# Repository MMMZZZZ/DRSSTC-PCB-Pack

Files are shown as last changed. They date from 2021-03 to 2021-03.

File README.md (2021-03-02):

I created a [new version of the UD2.7 THT](/ud27c%20thru%20hole#readme). No other changes, so here's the original readme:

Dual Resonant Solid State Tesla Coil and Solid State Tesla Coil PCB pack.
Copyright (C) 2018 by Daniel L. Marks, licensed under the Created Commons CC-BY-SA 4.0.

These are PCBs for use in DRSSTC/SSTC devices.  They are projects using
the free and open source Kicad software (kicad-pcb.org) version 4.0.7, so these projects
may be modified using this software.  Each file includes the following:

1.  Kicad project, so it can be modified or improved
2.  PDF Schematic
3.  Bill of materials, to refer to when assembling
4.  PNG circuit board picture, to refer to when assembling
5.  Gerber files

The projects, except for the interrupters, are 100 by 100 mm boards with 90 by 90 mm
mounting hole spacing.  These boards may be stacked using M3 spacers. Board of this 
size can often be fabricated for $5 (without shipping) from PCB manufacturers such as
Seeedstudio.  You can save on shipping per board if you have several of
these made at a time, for example, the driver, interrupter, and a bridge board.  

The projects are as follows:

ud27c - a through hole version of the Universal Tesla coil driver, version 2.7C.
          This is based on a design originally by Steve Ward and refined by others including
          Eric Goodchild and Gao Guangyan.  It has substituted the through-hole parts 
          IRF540N/IRF9540N complementary MOSFET pair for the FDD8424H dual MOSFET part.
          It includes phase lead, unlike the Universal Driver v1.3.

ud29 - an experimental version of ud27c that includes skip pulse functionality.  Pulse skip is
          enabled or disabled using a jumper, so it may be used as a normal DRSSTC controller.
		  The board has been built and worked for my coil.
		  
PSoc5-power - a through-hole version of the Universal Driver 3 by Steve Ward and Jens Kerrinnes
          based on the PSoC5 system-on-chip. This includes the functionality for temperature,
		  bus voltage, and bus current sensing.	 This is experimental.  It uses the CYC8KIT-059
		  dev board plugged into the PCB using pin header sockets.

interrupter - a DRSSTC interrupter based on Steve Ward's burst mode interrupter.  It
          includes a place for the IFE97 LED optical fiber transmission unit.  The ability
          to include an external pulse trigger signal has been included for use with audio
          sources.  Also includes a spot on the board for a OneTesla 
		  ATTINY85-based MIDI interrupter which may be flashed with the OneTesla code through
		  the ICSP interface.

lineinterrupter - an experimental interrupter that interrupts on the peak of the AC cycle.
           Interrupting only at the peak of the AC cycle is intended to improve the power factor
		   by minimizing the inrush of current into the bus capacitors as the magnitude of
		   the voltage increases.  
		  
NOTE: You need to flash the included firmware on your ATTINY85 for the MIDI interrupter to work.
Instructions are in the folder "oneTesla-usbInterrupter-software".
		  
half-bridge-sstc - a half-bridge/full-bridge driver designed by myself
          that can either self-oscillate, or take an extetrnal antenna input from a
          Solid State Tesla Coil.  It includes overcurrent and undervoltage protection.
	  
half-bridge-transistor - a layout for a two TO-247 transistor half-bridge that includes
          an area for the capacitor divider network.  Note the polarity on the gates indicated
          on the silkscreening always indicates the negative and positive voltage side of
          the gate; wire the phases of the gates accordingly (oppositely in this case).  This
          convention is followed for all of the layouts.  Space is included for both
          supply bypass/DC Link capacitors and snubber capacitors.
	  
full-bridge-transistor - a layout for a four TO-247 transistor full-bridge.  Space is included
          for supply bypass DC/Link capacitors and snubber capacitors.  The two high-side gates
          should have their polarities wired oppositely, the two low-side gates should
          have their polarities wired oppositely, and the high and low-side gates of each half-bridge
          should be have their polarities wired oppositely.
	  
half-bridge-multi - a layout for an eight TO-247 transistor half-bridge, with four transistors
          of each side of the half-bridge.  The transistors should have a positive temperature
          coefficient to share current more equally.  The high and low-side gates should have their
          polarities wired oppositely.
	  
full-bridge-multi - a layout for an eight TO-247 transistor full-bridge, with two transistors on
          each side of each half bridge.  The two high-side gates should have their 
          polarities wired oppositely, the two low-side gates should have their polarities
          wired oppositely, and the high and low-side gates of each half-bridge
	      should be have their polarities wired oppositely.

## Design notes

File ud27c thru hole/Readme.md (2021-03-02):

# UD2.7 Through Hole

## Description

This folder contains the KiCad files for the through hole edition of the UD2.7 DRSSTC driver. It uses the schematic and the footprints from the original UD2.7 THT profdc9 made. However, the layout is completely new.

Features:

* PCB can be manufactured as standard double sided PCB *and* as **single sided**. 
	* Top layer only contains straight connections that can be replaced by jumper wires. Note that this assumes you're using sockets for the ICs.
	* No layout modifications needed for single or double side manufacturing. 
	* Single side should be easier to manufacture at home. 
* All TO220 parts are on the same side of the PCB. One common (isolated!) heatsink can be used.
* Optical inputs and status LEDs are on the opposite side of the heatsink. All inputs are grouped on the left side, the GDT output is on the right.
* All testpoints are on the edge of the PCB. 
* All terminals, jumpers and tespoints are labeled. DC In and testpoints have the pinout marked as well.
* PCB size: 99mm x 99mm
* [Interactive BOM](http://htmlpreview.github.io/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). An HTML document that allows you to visualize what part sits where. Great help during assembly! It allows highlighting nets, too, which is very useful for debugging. If you want to use it offline, right click and save as on the following link: [Interactive BOM, raw file](https://github.com/MMMZZZZ/DRSSTC-PCB-Pack/raw/master/ud27c%20thru%20hole/bom/ud27c%20Interactive%20BOM.html).

## Preview

Here are some pics. Since the layout was made with single side manufacturing in mind, the routing doesn't look that clean but it should work. Power and ground are somewhat star like. 

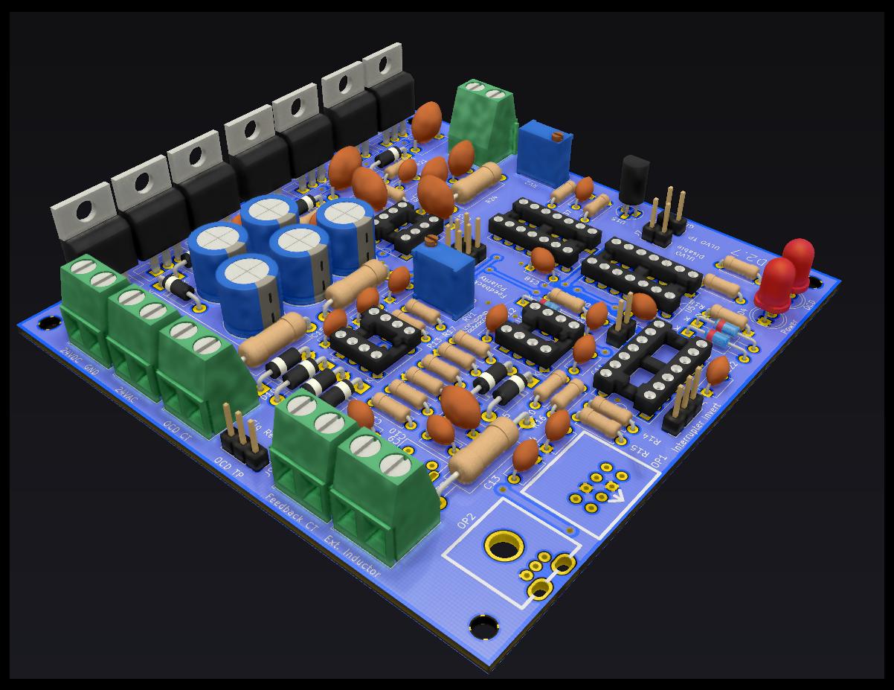
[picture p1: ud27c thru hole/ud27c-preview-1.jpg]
UD2.7 THT Rendering 1


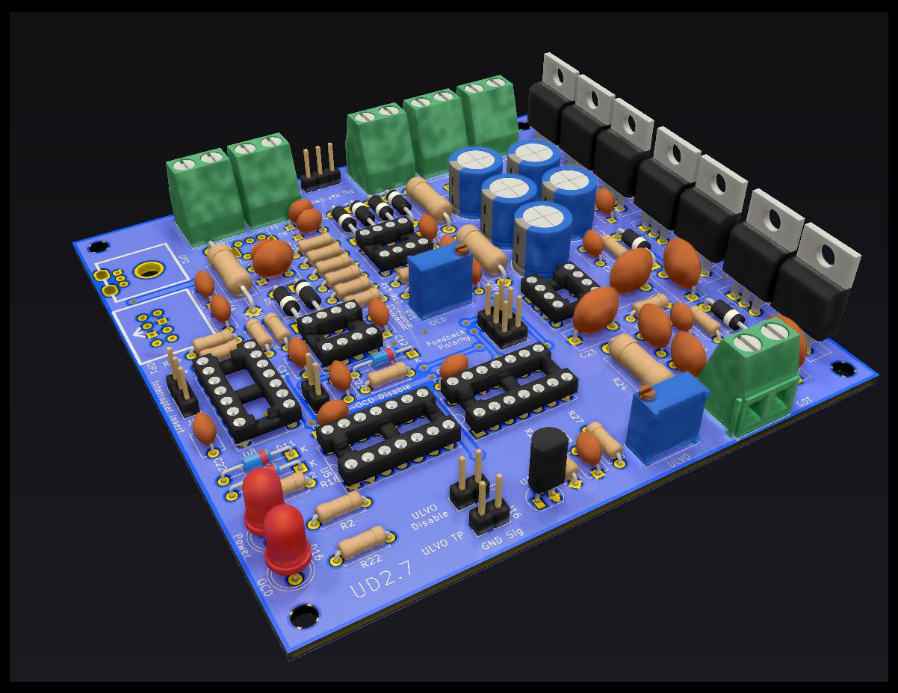
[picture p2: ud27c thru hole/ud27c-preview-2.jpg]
UD2.7 THT Rendering 2


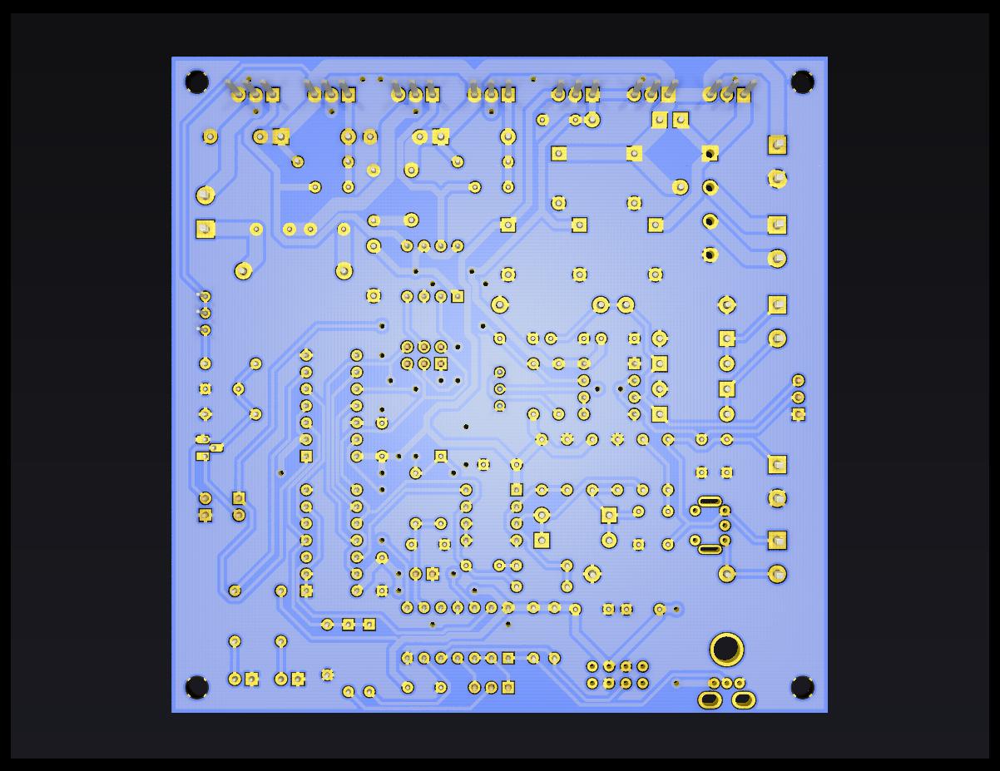
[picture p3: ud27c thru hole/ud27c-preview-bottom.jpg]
UD2.7 THT Bottom


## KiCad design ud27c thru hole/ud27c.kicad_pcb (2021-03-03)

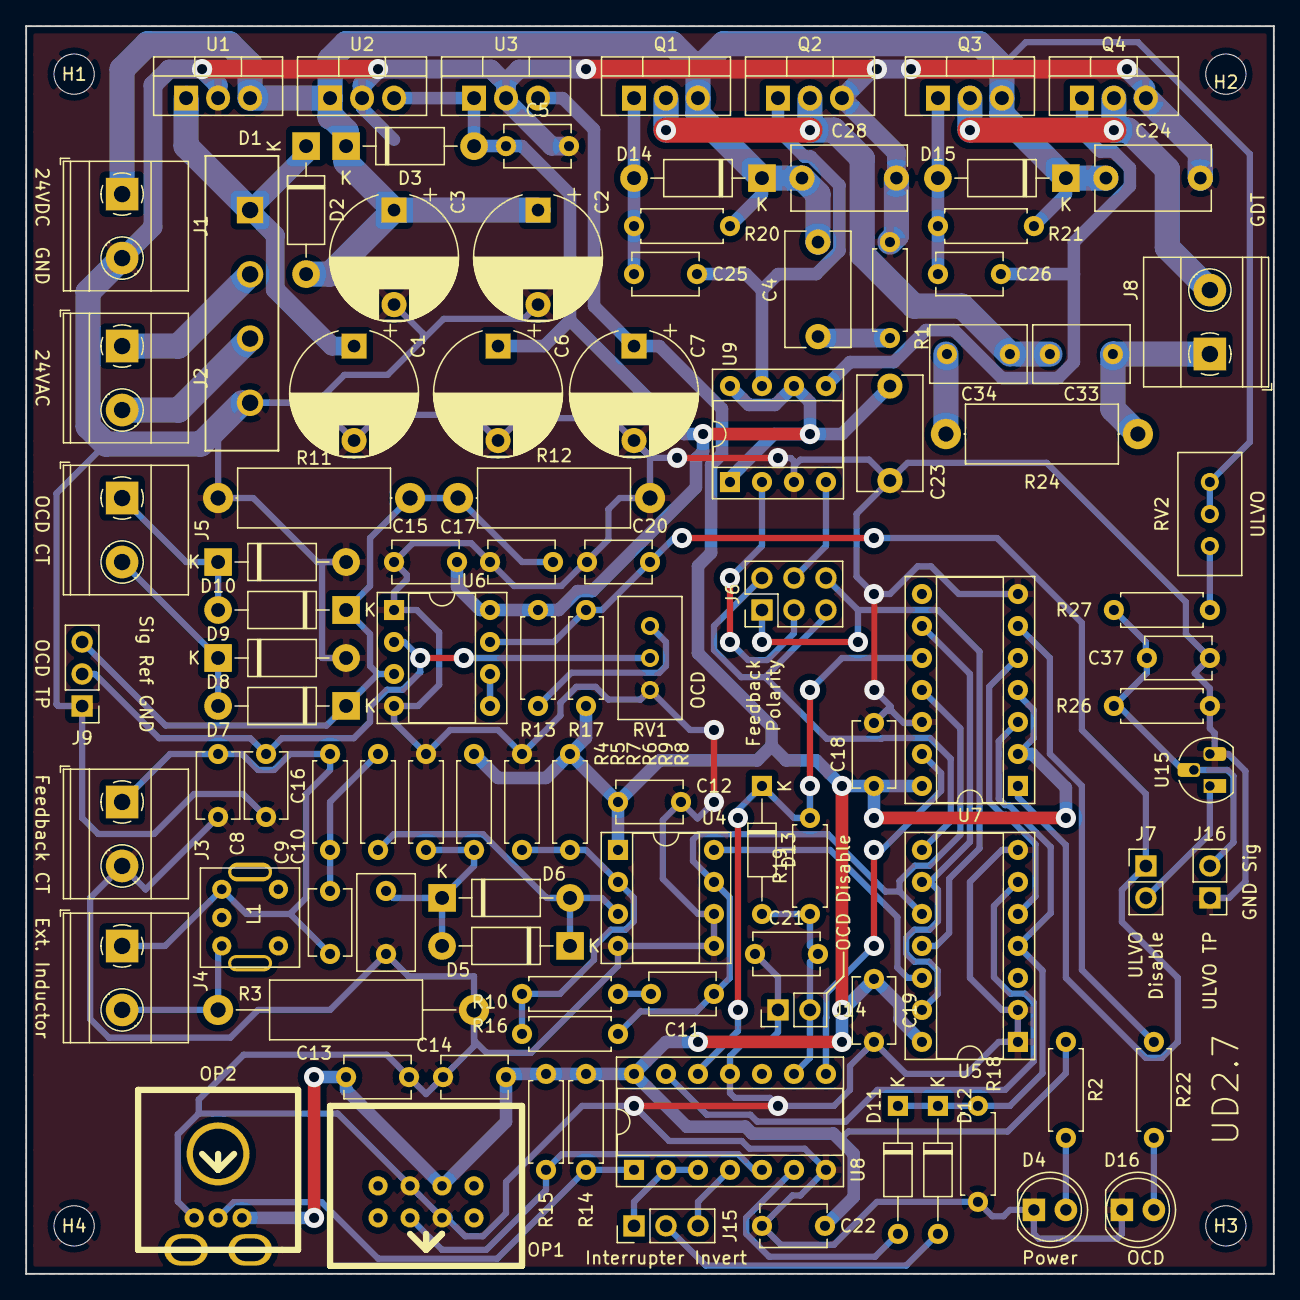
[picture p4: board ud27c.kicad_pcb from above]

Board: 2 copper layers, 99.1 x 99.1 mm, 106 parts (0 on the bottom side), 55 nets.

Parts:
C1, C2, C3: 100 uF; CP_Radial_D10.0mm_P7.50mm
C4, C24, C28: 4.7 uF; C_Disc_D9.0mm_W5.0mm_P7.50mm
C5, C9, C12, C13, C14, C15, C16, C18, C19, C22, C25, C26: 0.1 uF; C_Disc_D5.1mm_W3.2mm_P5.00mm
C6, C7: 330 uF; CP_Radial_D10.0mm_P7.50mm
C8: 150 pF; C_Disc_D5.1mm_W3.2mm_P5.00mm
C10, C34: 1 uF; C_Disc_D7.5mm_W4.4mm_P5.00mm
C11, C17, C20, C37: 1 nF; C_Disc_D5.1mm_W3.2mm_P5.00mm
C21: 10 nF; C_Disc_D5.1mm_W3.2mm_P5.00mm
C23: 1.0 uF; C_Disc_D9.0mm_W5.0mm_P7.50mm
C33: 2.2 uF; C_Disc_D7.5mm_W4.4mm_P5.00mm
D1: D_Bridge_-AA+; Diode_Bridge_18.5x5.5_4321
D2, D3: 1N4007; D_DO-41_SOD81_P10.16mm_Horizontal
D4: PWR-LED; LED_D5.0mm
D5, D6, D7, D8, D9, D10: 1N5818; D_DO-41_SOD81_P10.16mm_Horizontal
D11, D12, D13: 1N4148; D_DO-35_SOD27_P10.16mm_Horizontal
D14, D15: 1N4148; D_DO-41_SOD81_P10.16mm_Horizontal
D16: OCD-LED; LED_D5.0mm
H1, H2, H3, H4: MountingHole_Pad; MountingHole_3.2mm_M3
J1: +24V-; TerminalBlock_Phoenix_MKDS-1,5-2-5.08_1x02_P5.08mm_Horizont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
J2: 24VAC; TerminalBlock_Phoenix_MKDS-1,5-2-5.08_1x02_P5.08mm_Horizont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
J3: FB-CT; TerminalBlock_Phoenix_MKDS-1,5-2-5.08_1x02_P5.08mm_Horizont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
J4: FB-IND; TerminalBlock_Phoenix_MKDS-1,5-2-5.08_1x02_P5.08mm_Horizont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
J5: OCD-CT; TerminalBlock_Phoenix_MKDS-1,5-2-5.08_1x02_P5.08mm_Horizont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
J6: FB-POLARITY; PinHeader_2x03_P2.54mm_Vertical
J7: UV-DIS; PinHeader_1x02_P2.54mm_Vertical
J8: GDT; TerminalBlock_Phoenix_MKDS-1,5-2-5.08_1x02_P5.08mm_Horizont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
J9: OCD-TP; PinHeader_1x03_P2.54mm_Vertical
J14: OCD-DIS; PinHeader_1x02_P2.54mm_Vertical
J15: INT-POLARITY; PinHeader_1x03_P2.54mm_Vertical
J16: UV-TP; PinHeader_1x02_P2.54mm_Vertical
L1: SLOT7; CoilCraft_Slot_7
OP1: OPF2412T
OP2: IFD95
Q1, Q3: IRF9540N; TO-220-3_Vertical
Q2, Q4: IRF540N; TO-220-3_Vertical
R1: 1R; R_Axial_DIN0207_L6.3mm_D2.5mm_P7.62mm_Horizontal
R2, R7, R9, R10, R22, R26: 470R; R_Axial_DIN0207_L6.3mm_D2.5mm_P7.62mm_Horizontal
R3: 51R; R_Axial_DIN0414_L11.9mm_D4.5mm_P20.32mm_Horizontal
R4, R16: 100k; R_Axial_DIN0207_L6.3mm_D2.5mm_P7.62mm_Horizontal
R5, R6, R8, R14, R15, R17, R18, R20, R21, R27: 1k; R_Axial_DIN0207_L6.3mm_D2.5mm_P7.62mm_Horizontal
R11, R12: 5.1R; R_Axial_DIN0414_L11.9mm_D4.5mm_P15.24mm_Horizontal
R13: 1.8k; R_Axial_DIN0207_L6.3mm_D2.5mm_P7.62mm_Horizontal
R19: 10k; R_Axial_DIN0207_L6.3mm_D2.5mm_P7.62mm_Horizontal
R24: 15R; R_Axial_DIN0414_L11.9mm_D4.5mm_P15.24mm_Horizontal
RV1: 10k; Potentiometer_Bourns_3296W_Vertical
RV2: 5k; Potentiometer_Bourns_3296W_Vertical
U1: LM7824_TO220; TO-220-3_Vertical
U2: LM7812_TO220; TO-220-3_Vertical
U3: LM7805_TO220; TO-220-3_Vertical
U4: TL3116; DIP-8_W7.62mm_Socket
U5: 74HC08; DIP-14_W7.62mm_Socket
U6: LM311; DIP-8_W7.62mm_Socket
U7: 74HC74; DIP-14_W7.62mm_Socket
U8: 74HC14; DIP-14_W7.62mm_Socket
U9: UCC27243; DIP-8_W7.62mm_Socket
U15: MC34164; TO-92L_HandSolder

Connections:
+5V: C7.1, C12.1, C13.1, C14.1, C18.1, C19.1, C22.2, OP1.2, OP2.3, R2.1, R6.1, R8.1, R14.2, R15.1, R17.2, U3.3, U4.1, U5.14, U7.2, U7.4, U7.14, U8.14
+12V: C5.1, C6.1, C15.2, C23.2, D3.2, R13.1, U2.3, U3.1, U6.8, U9.1, U9.6, U9.8
+24V: C2.1, C3.1, C4.1, C24.1, C28.1, D2.2, D3.1, D14.1, D15.1, J1.1, Q1.3, Q3.3, R20.1, R21.1, RV2.2, RV2.3, U1.3, U2.1
GND: C1.2, C2.2, C3.2, C5.2, C6.2, C7.2, C8.2, C10.1, C12.2, C13.2, C14.2, C15.1, C16.1, C17.2, C18.2, C19.2, C20.1, C21.1, C22.1, C23.1, C24.2, C28.2, C37.1, D1.1, D4.1, D8.2, D10.2, D16.1, H1.1, H2.1, H3.1, H4.1, J1.2, J3.2, J9.1, J14.1, J16.1, OP1.3, OP1.7, OP2.1, Q2.3, Q4.3, R1.2, R3.2, R7.2, R9.2, R11.2, R12.2, R18.1, R26.2, RV1.3, U1.2, U2.2, U3.2, U4.4, U4.5, U4.6, U5.1, U5.2, U5.7, U6.1, U6.4, U7.7, U7.12, U8.7, U8.11, U9.3, U15.3
unnamed: C1.1, D1.4, D2.1, U1.1
unnamed: C4.2, R1.1
unnamed: C8.1, C9.2, J3.1, J4.1, L1.3, R4.2
unnamed: C9.1, R4.1, R5.2
unnamed: C10.2, D5.2, D6.1, R6.2, R7.1
unnamed: C11.1, R16.2, U4.7, U5.10, U7.11
unnamed: C11.2, R10.2
unnamed: C16.2, J9.2, RV1.2, U6.2
unnamed: C17.1, D7.1, D9.1, J9.3, R11.1, R12.1, U6.3
unnamed: C20.2, J7.1, R17.1, U6.7, U7.1
unnamed: C21.2, D13.2, J14.2, R19.1, U8.9
unnamed: C25.1, D14.2, Q1.1, R20.2
unnamed: C25.2, Q2.1, U9.7
unnamed: C26.1, D15.2, Q3.1, R21.2
unnamed: C26.2, Q4.1, U9.5
unnamed: C33.1, C34.1, Q1.2, Q2.2
unnamed: C33.2, J8.1, R24.2
unnamed: C34.2, R24.1
unnamed: C37.2, J16.2, R26.1, R27.2, U15.2
unnamed: D1.2, J2.2
unnamed: D1.3, J2.1
unnamed: D4.2, R2.2
unnamed: D5.1, D6.2, R5.1, U4.3
unnamed: D7.2, D8.1, J5.2
unnamed: D9.2, D10.1, J5.1
unnamed: D11.1, D12.1, R18.2, U5.4, U7.3
unnamed: D11.2, U8.6
unnamed: D12.2, J15.2
unnamed: D13.1, R19.2, U7.10, U8.12
unnamed: D16.2, R22.2
unnamed: J4.2, L1.1, R3.1
unnamed: J6.1, J6.6, U5.11
unnamed: J6.2, J6.5, U5.8
unnamed: J6.3, U9.2
unnamed: J6.4, U9.4
unnamed: J7.2, U15.1
unnamed: J8.2, Q3.2, Q4.2
unnamed: J15.1, U8.2, U8.3
unnamed: J15.3, U8.4
unnamed: OP1.6, R15.2, U8.5
unnamed: OP2.2, R14.1, U8.1
unnamed: R8.2, R9.1, R10.1, R16.1, U4.2
unnamed: R13.2, RV1.1
unnamed: R22.1, U7.6
unnamed: R27.1, RV2.1
unnamed: U4.8, U5.12
unnamed: U5.5, U7.5
unnamed: U5.6, U8.13
unnamed: U5.9, U5.13, U7.9
unnamed: U6.5, U6.6
unnamed: U7.13, U8.8

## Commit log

2021-03-01 Migrated to v5.1.9 (only as far as necessary), started layout
    A lot of schematic symbols that are part of the standard library (like +24V) are taken from the rescure library and should be changed to the standard ones. Todo for a future, bored version of me.
    [ud27c-2021-02-28-10-31-12.sch, ud27c-2021-03-01-19-53-57.sch, ud27c.kicad_pcb]
2021-03-02 Interactive BOM
2021-03-02 Trying to fix BOM Link
